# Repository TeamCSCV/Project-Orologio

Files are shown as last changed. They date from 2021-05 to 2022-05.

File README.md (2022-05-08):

# Digital Alarm Clock

Lab project for the second semester at ENTC-UoM

The purpose of this project is to present the design and construction of a digital clock fitted with an alarm circuit that operates at a frequency of 16MHz. This digital alarm clock is designed such that it uses a keypad for giving inputs, buttons to control the menu, an LCD display to visualize current time and date, and a buzzer to ring the alarm tones. Menu options range from core clock functionalities like setting the current date and time to setting the alarm time and the alarm tones.

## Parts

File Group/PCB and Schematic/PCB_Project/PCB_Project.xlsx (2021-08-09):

Comment | Description | Designator | Footprint | LibRef | Quantity
330nF | Aluminum Electrolytic Capacitor, 100 uF, +/- 20%, 50 V, -40 to 85 degC, 2-Pin THD, RoHS, Bulk | C1 | CAPPR65-350-1150X800X1250 | CMP-1665-00042-2 | 1
100nF | Aluminum Electrolytic Capacitor, 100 uF, +/- 20%, 50 V, -40 to 85 degC, 2-Pin THD, RoHS, Bulk | C2, C5, C6 | CAPPR65-350-1150X800X1250 | CMP-1665-00042-2 | 3
22pF | Cap Ceramic 22pF 50V C0G ±5% Radial 5mm +125°C Automotive Bulk | C3, C4 | FP-RCE0K1-MFG | CMP-06035-004895-1 | 2
1N4001 | Standard Recovery Rectifier, 2-Pin Axial_Lead, Pb-Free, Bulk Bag | D1 | ONSC-AXIAL_LEAD-2-59-10_P | CMP-0902-00117-1 | 1
Power | CONN HEADER VERT 2POS 2MM | JST1 | FP-440054-2-MFG | CMP-03369-000005-1 | 1
Buzzer | CONN HEADER VERT 2POS 2MM | JST2 | FP-440054-2-MFG | CMP-03369-000005-1 | 1
Potentiometer | Male Header, Pitch 2 mm, 1 x 3 Position, Height 6 mm, Tail Length 3.4 mm, -25 to 85 degC, RoHS, Bulk | JST3 | JST-B3B-PH-K-S-3_V | CMP-2000-05164-1 | 1
UP_BTN | SWITCH TACTILE SPST-NO 0.05A 24V | KEY1 | FP-1825910-2-0 | CMP-03407-000004-1 | 1
DOWN_BTN | SWITCH TACTILE SPST-NO 0.05A 24V | KEY2 | FP-1825910-2-0 | CMP-03407-000004-1 | 1
SELECT_BTN | SWITCH TACTILE SPST-NO 0.05A 24V | KEY3 | FP-1825910-2-0 | CMP-03407-000004-1 | 1
BACK_BTN | SWITCH TACTILE SPST-NO 0.05A 24V | KEY4 | FP-1825910-2-0 | CMP-03407-000004-1 | 1
RST_BTN | SWITCH TACTILE SPST-NO 0.05A 24V | KEY5 | FP-1825910-2-0 | CMP-03407-000004-1 | 1
LCD Connector | THT Vertical Pin Header WR-PHD, Pitch 2.54 mm, Single Row, 12 pins | P1 | 61301211121 | CMP-1502-01086-1 | 1
Keypad | THT Vertical Pin Header WR-PHD, Pitch 2.54 mm, Single Row, 7 pins | P2 | 61300711121 | CMP-1502-01074-1 | 1
RTC Module | THT Vertical Pin Header WR-PHD, Pitch 2.54 mm, Single Row, 4 pins | P3 | 61300411121 | CMP-1502-01064-1 | 1
BC547B | NPN Bipolar Transistor | Q1 | ONSC-TO-92-3-29-11 | NPN | 1
1K | Resistor | R1, R2, R3, R4, R5, R6, R7, R8 | AXIAL-0.3 | Res1 | 8
470R | Resistor | R9, R10, R11 | AXIAL-0.3 | Res1 | 3
220R | Resistor | R12, R13 | AXIAL-0.3 | Res1 | 2
10K | Resistor | R14 | AXIAL-0.3 | Res1 | 1
ATmega328P-PU | 8-bit AVR Microcontroller, 32KB Flash, 1KB EEPROM, 2KB SRAM, 28-pin PDIP, Industrial Grade (-40°C to 85°C) | U1 | 28P3 | CMP-0095-00013-2 | 1
L7805ACV | Positive Voltage Regulator, 5V, 3-Pin TO-220 | U2 | TO220 | CMP-0244-00484-1 | 1
16MHz | Resistance Weld Thru-Hole Crystal, 16 MHz, -20 to 70 degC, 2-Pin THD, RoHS, Bulk | XTAL1 | FOX-FOXSLF160-20 | CMP-1749-00003-1 | 1

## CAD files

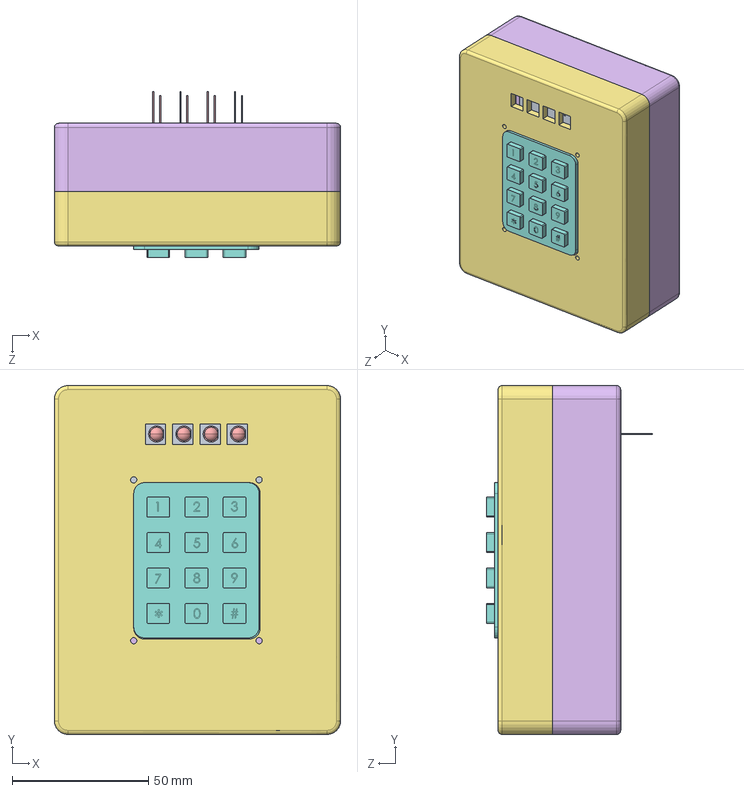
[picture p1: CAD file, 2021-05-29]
Individual/Key Input (Senuri)/Solidworks/keyInput_.SLDASM
105.0 x 128.0 x 61.0 mm
Extruded.step
Extruded-0.step x 2
Extruded-1.step x 2
Extruded-2.step x 4
Extruded-3.step x 2
Extruded-4.step x 2
Extruded-5.step x 2
Extruded-6.step x 2
Extruded-7.step x 4
Extruded-8.step x 2
Extruded-9.step x 2
Extruded-10.step x 4
Extruded-11.step x 2
Extruded-12.step x 2
Extruded-13.step
Extruded-14.step
Extruded-15.step x 3
Extruded-16.step x 3
Extruded-17.step
WP7113.step x 4
test_bottom
test_top
Keypad 3x4.step
9V Battery Holder

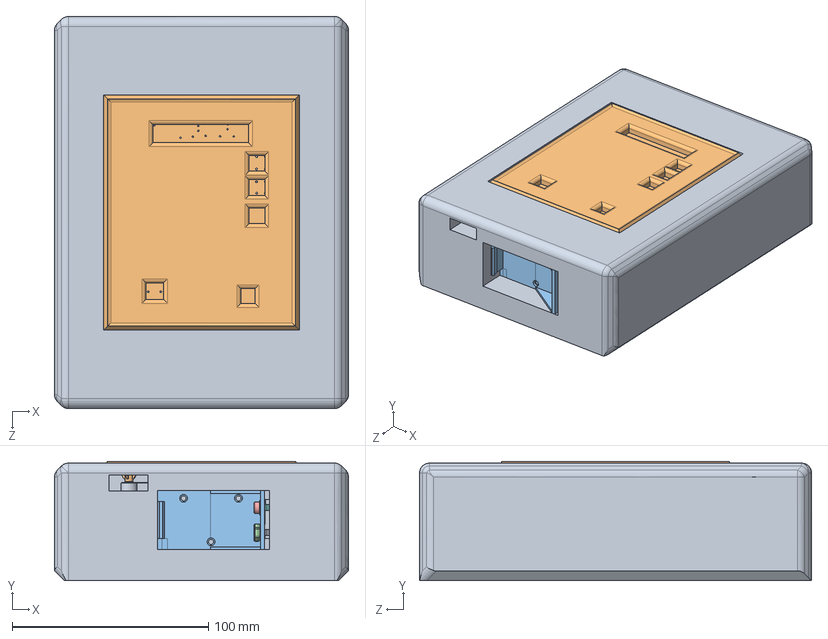
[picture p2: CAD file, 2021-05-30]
Individual/Alarm Timing (Vinuja)/Solidworks enclosure/ProjectAssembly.SLDASM
150.0 x 60.9 x 200.0 mm
labProject_micro_bottom
Body_Housing.step
Body_Anode.step
Body_Cathode.step
Eyelet_bended_Cathode.step
Eyelet_bended_Anode.step
labProject_micro_top

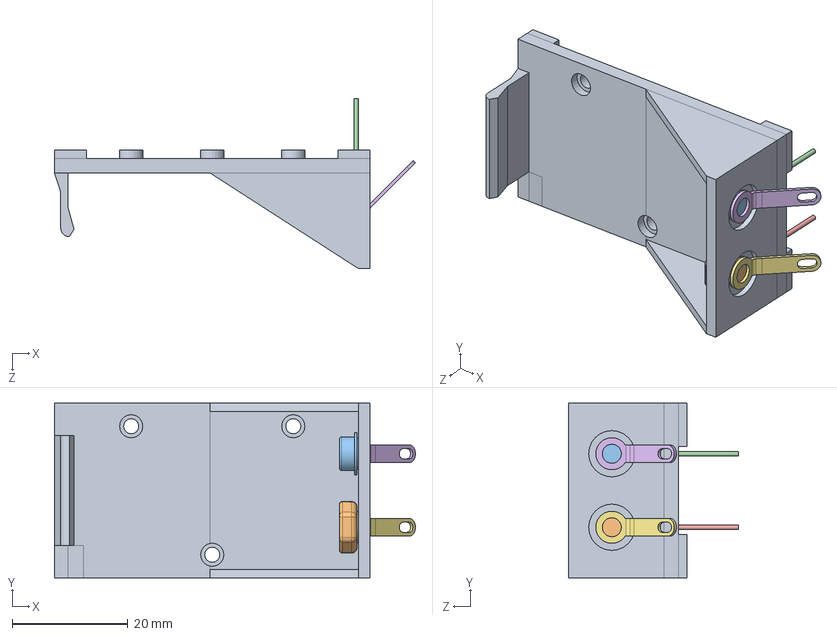
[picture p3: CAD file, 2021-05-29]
Individual/Alarm Timing (Vinuja)/Solidworks enclosure/BatteryHolder_9V_Eyelet_or_Pins.SLDASM
62.4 x 30.2 x 29.4 mm
Body_Housing.step
Body_Anode.step
Body_Cathode.step
Eyelet_bended_Cathode.step
Eyelet_bended_Anode.step

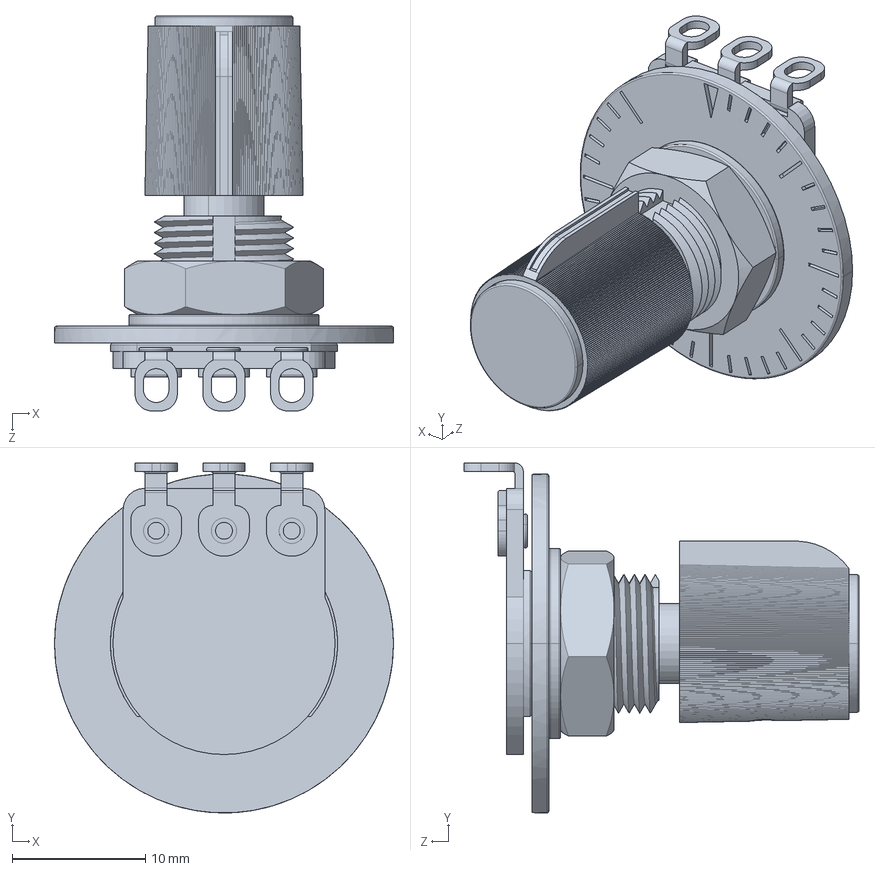
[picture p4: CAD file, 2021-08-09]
Group/Enclosure/100 ohm Sigle Potentiometer Assembly.SLDPRT
25.4 x 26.2 x 29.6 mm

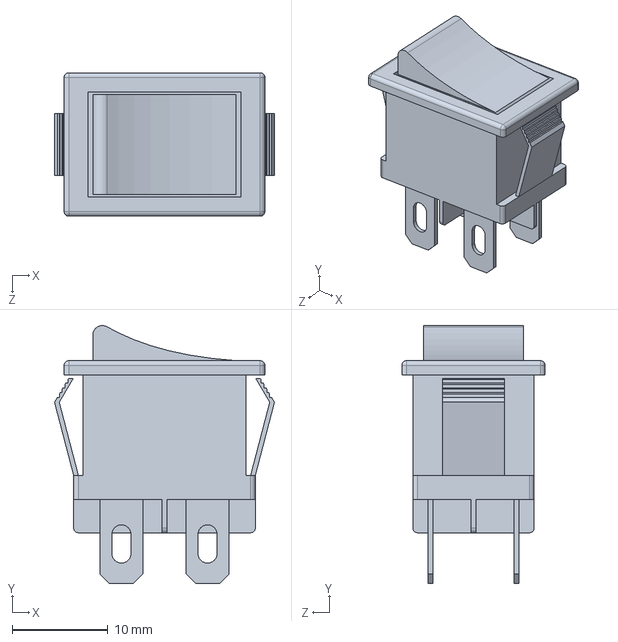
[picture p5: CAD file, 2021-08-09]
Group/Enclosure/64_Switch.step.SLDPRT
23.0 x 27.0 x 15.0 mm

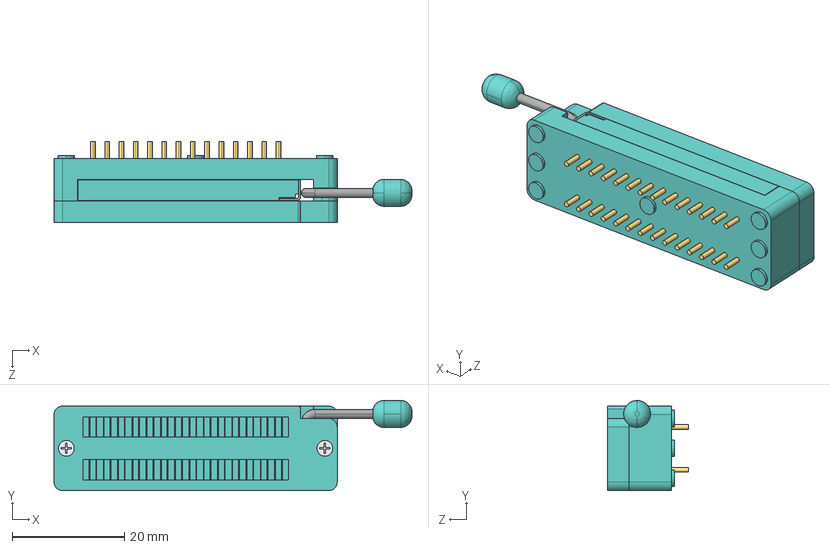
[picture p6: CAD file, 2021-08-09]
Group/PCB and Schematic/PCB_Project/Models/User Library-ZIF-Socket-28-pin.STEP
63.7 x 16.0 x 14.4 mm
Contacts
Pins001
Screw002
Bottom-Shape
Lever-Tip
Top-Shape
Push-Bar
Lever-Bar
Screw001

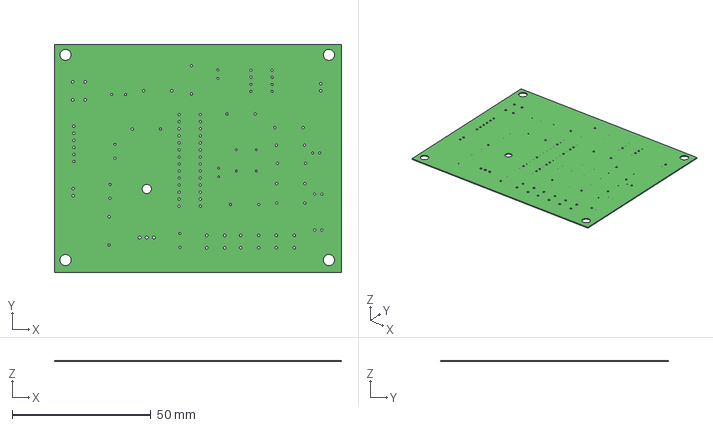
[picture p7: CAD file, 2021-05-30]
Individual/Alarm Timing (Vinuja)/Solidworks enclosure/AlarmTiming.step
103.5 x 82.2 x 0.411 mm

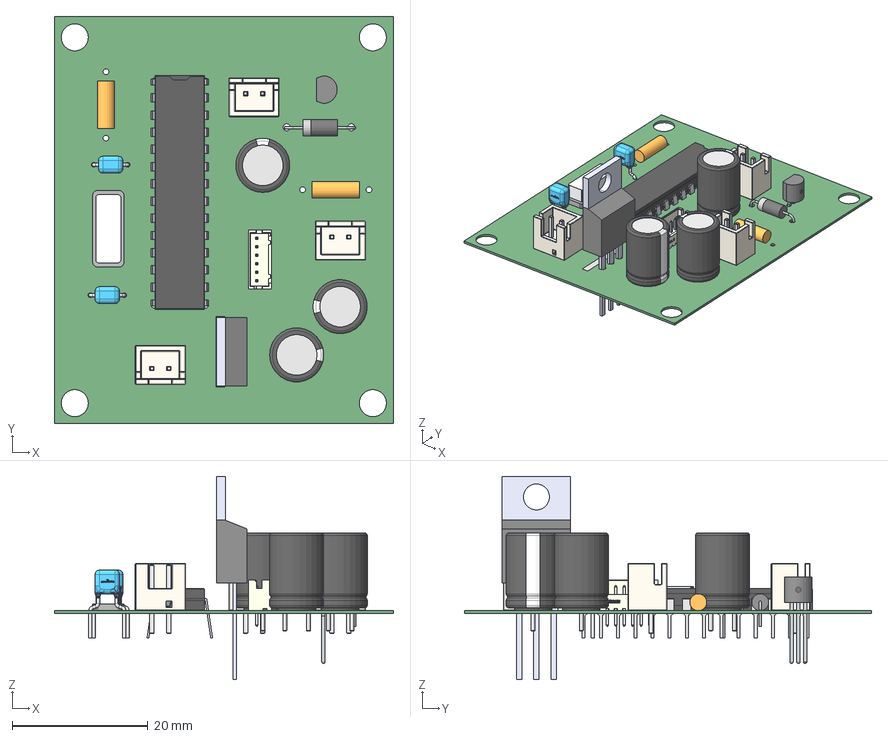
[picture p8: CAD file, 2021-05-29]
Individual/Audio Output (Chathushka)/2nd Stage/Solid Works/PCB1.step
50.0 x 60.1 x 30.0 mm
B2B-XH-A x 3
JST_Logo_adjustable x 3
L7805ACV
Extruded x 3
atmega328p-pu
BC547-B
M30-610XXXX_MOULDING
M30-610XXXX_PIN x 6
Harwin
Aluminum_electrolytic_capacitor_radial_D8_H11.5_PinD0.6_Pitch3.5_ nominal_black x 15
leads x 2
logo x 2
Diode_1N4001

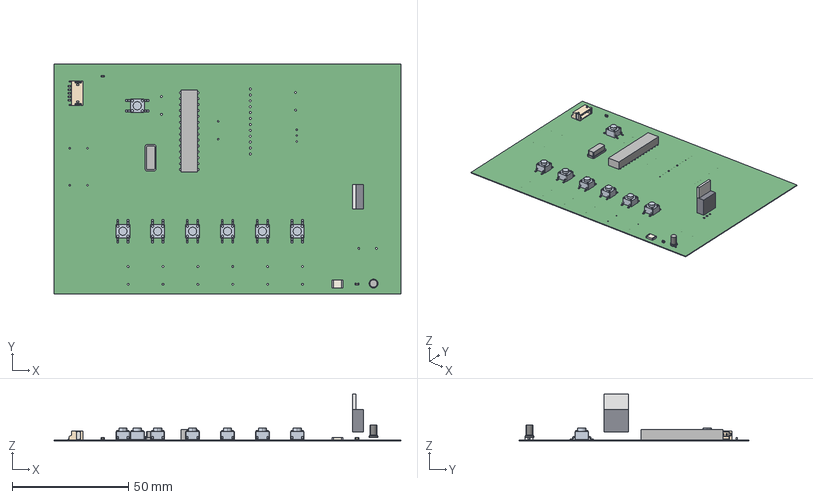
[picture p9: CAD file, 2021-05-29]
Individual/Display (Chamith)/PCB_Project/PCB1.step
149.2 x 99.1 x 20.1 mm
6481xx131822_PIN x 5
6481xx131822_PATTE x 2
TDK_Logo x 2
Extruded x 11
c-4-1437565-2-s-3d x 7

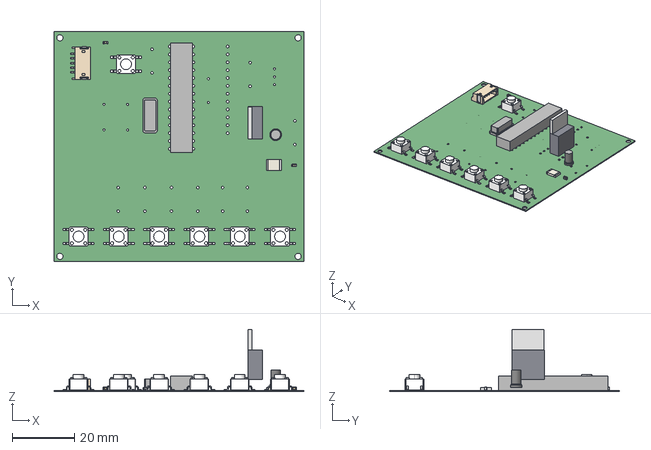
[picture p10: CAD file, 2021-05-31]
Individual/Display (Chamith)/Solidworks file/PCB2.step
80.6 x 74.2 x 20.1 mm

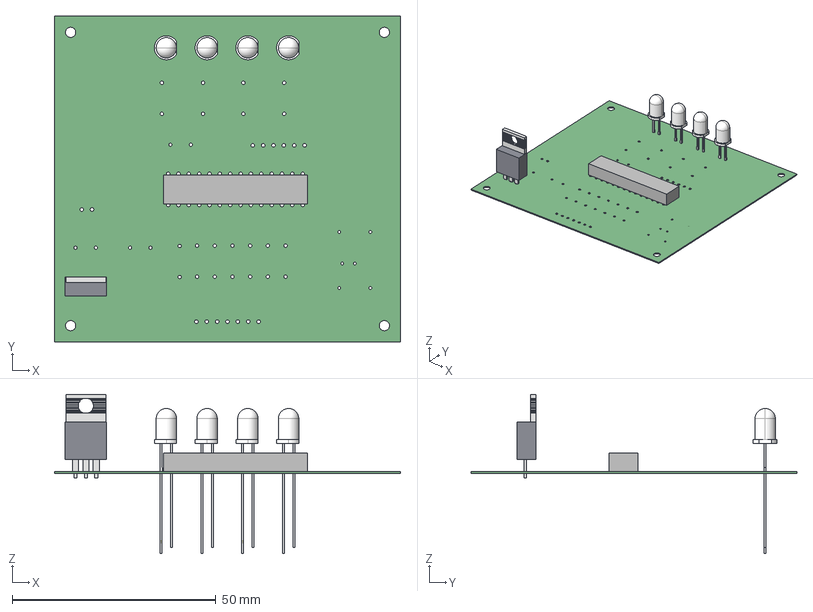
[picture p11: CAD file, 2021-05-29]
Individual/Key Input (Senuri)/PCB-KeyInput/keyInput1.step
85.0 x 80.0 x 39.1 mm
Extruded x 42
WP7113 x 4

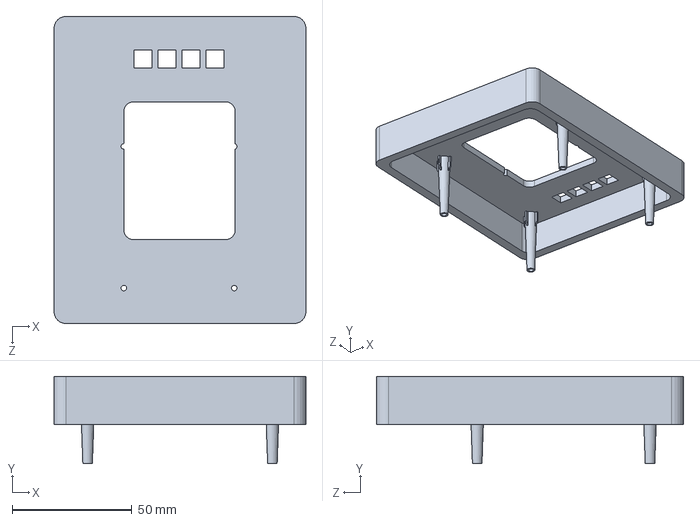
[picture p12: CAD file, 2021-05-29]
Individual/Key Input (Senuri)/Solidworks/test_top.SLDPRT
105.0 x 36.3 x 128.0 mm

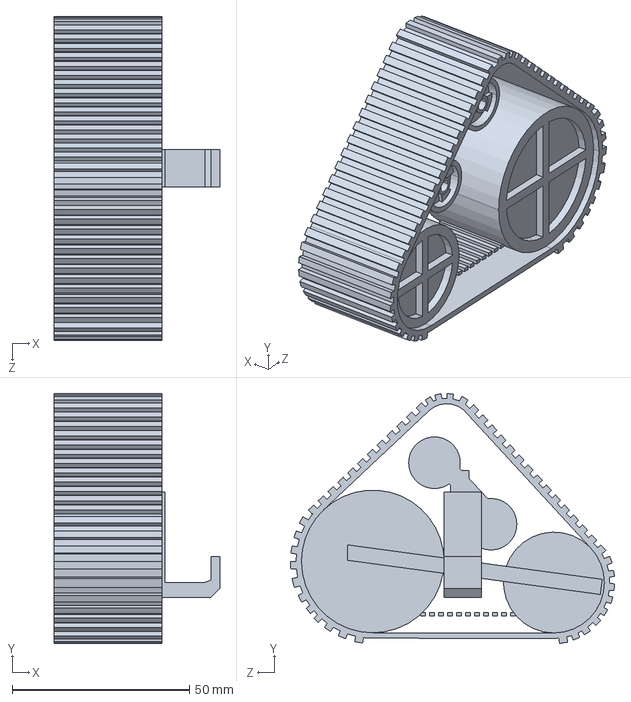
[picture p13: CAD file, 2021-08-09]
Group/Enclosure/wheel 2.SLDPRT
46.7 x 70.5 x 91.4 mm

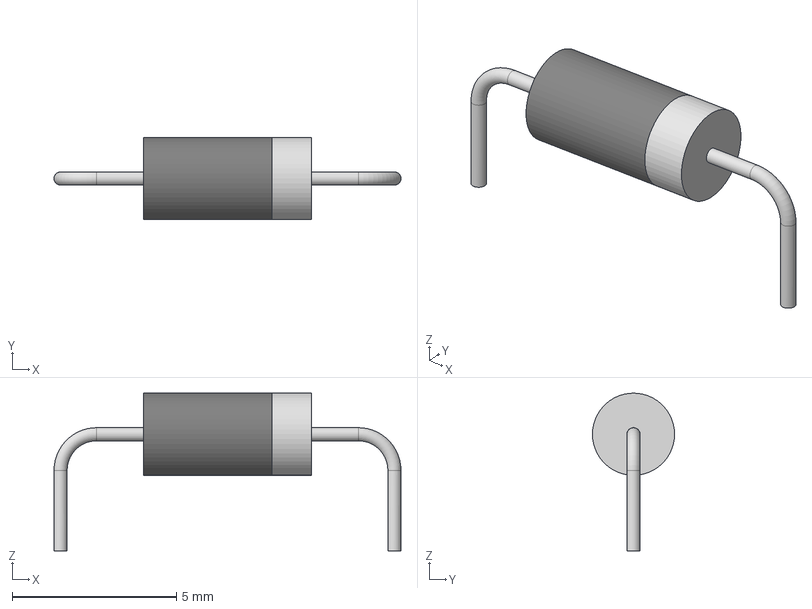
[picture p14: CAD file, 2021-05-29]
Group/PCB and Schematic/PCB_Project/Models/Diode 1N4001.stp
10.6 x 2.50 x 4.80 mm

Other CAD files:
Individual/Alarm Timing (Vinuja)/Solidworks enclosure/Open CASCADE STEP translator 6.8 6.1.1.step.SLDPRT
Individual/Audio Output (Chathushka)/2nd Stage/Solid Works/Bouton poussoir.SLDPRT
Individual/Display (Chamith)/PCB_Project/PCB2.step
Individual/Display (Chamith)/Solidworks file/smt_resistor222.STEP.SLDPRT
Group/Enclosure/64_Switch.STEP
Group/Enclosure/BATTARY HOLDER.SLDPRT
Group/Enclosure/Matrix Keypad 12 Key (4X3).SLDPRT
Group/Enclosure/MirrorRight Side Arm.SLDPRT
Group/Enclosure/Mirrorwheel 2.SLDPRT
Group/Enclosure/Part46.SLDPRT
Group/Enclosure/Part5.SLDPRT
Group/Enclosure/Right Side Arm.SLDPRT
Group/Enclosure/Right Side Arm.STEP
Group/Enclosure/TMB12A05.step
Group/Enclosure/TMB12A05.step.SLDPRT
Group/Enclosure/upper part.SLDPRT
Group/Enclosure/wheel.STEP
Group/PCB and Schematic/PCB_Project/Models/1N4001--3DModel-STEP-56544.STEP
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

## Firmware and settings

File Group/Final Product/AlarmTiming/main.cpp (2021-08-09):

#define __DELAY_BACKWARD_COMPATIBLE__
#define F_CPU 1000000UL

#include <avr/io.h>
#include <stdlib.h>
#include <stdio.h>
#include "ds1307.h"
#include "Settings.h"
#include "util/delay.h"
#include "Screen.h"
#include "Key_Pad.h"
#include "Tone.h"


Screen scrn;
Key_Pad key;
Tone t(3);


int main(void)
{
	ds1307_init();
	scrn.LCD_Init();
	while (1)
	{
		

		mainLoop();
			
	
	}
		
	
}

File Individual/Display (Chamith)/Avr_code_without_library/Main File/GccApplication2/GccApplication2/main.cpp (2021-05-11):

/*
 * display.cpp
 * Created by Ranathunga R.A.C.D 190501V
 */ 

#include <avr/io.h>
#define F_CPU 1000000UL			
#include <avr/io.h>			
#include <util/delay.h>			

#define LCD_Dir  DDRB			//LCD data port direction
#define LCD_Port PORTB			//LCD data port
#define RS PB0				   //register select pin
#define EN PB1 				  // Enable pin


void LCD_Command( unsigned char cmnd )     //function to initialize a command given as a hexadecimal number
{
	LCD_Port = (LCD_Port & 0x0F) | (cmnd & 0xF0); 
	LCD_Port &= ~ (1<<RS);		
	LCD_Port |= (1<<EN);		
	_delay_us(1);
	LCD_Port &= ~ (1<<EN);

	_delay_us(200);

	LCD_Port = (LCD_Port & 0x0F) | (cmnd << 4); 
	LCD_Port |= (1<<EN);
	_delay_us(1);
	LCD_Port &= ~ (1<<EN);
	_delay_ms(2);
}



void LCD_Char( unsigned char data )
{
	LCD_Port = (LCD_Port & 0x0F) | (data & 0xF0); 
	LCD_Port |= (1<<RS);		//RS = 1
	LCD_Port|= (1<<EN);
	_delay_us(1);
	LCD_Port &= ~ (1<<EN);

	_delay_us(200);

	LCD_Port = (LCD_Port & 0x0F) | (data << 4); 
	LCD_Port |= (1<<EN);
	_delay_us(1);
	LCD_Port &= ~ (1<<EN);
	_delay_ms(2);
}



void LCD_Init (void)			//Initialize the display
{
	LCD_Dir = 0xFF;			//LCD data direction is output
	_delay_ms(20);			
	
	LCD_Command(0x02);		
	LCD_Command(0x28);              
	LCD_Command(0x0c);              //Command - Display on Cursor off
	LCD_Command(0x06);              //Command - shift cursor to right
	LCD_Command(0x01);              //Command - Clear display
	_delay_ms(2);
}




void LCD_String (char *str)		//Writing a string on LCd display
{
	int i;
	for(i=0;str[i]!=0;i++)		
	{
		LCD_Char (str[i]);
	}
}



void LCD_Clear()             //Function to clear display and come back to home position
{
	LCD_Command (0x01);		
	_delay_ms(2);
	LCD_Command (0x80);		
}


void Time()             //Function to write time to display(Here I have used the test "Time". (I have to link RTC code here)
{
	LCD_Clear();
	LCD_String("Time...");
	_delay_ms(500);
}


void Select()            //What to do when the user press the select button
{
	LCD_Clear();
	LCD_String("Pressed Select");
	_delay_ms(500);
}

void Left()              //What to do when the user press the left arrow
{
	LCD_Clear();
	LCD_String("Pressed Left");
	_delay_ms(500);
}

void Right()              //What to do when the user press the right arrow
{
	
	LCD_Clear();
	LCD_String("Pressed Right");
	_delay_ms(500);
}

void Up()                  //What to do when the user press the up arrow
{
	LCD_Clear();
	LCD_String("Pressed Up");
	_delay_ms(500);
}

void Down()              //What to do when the user press the down arrow
{
	LCD_Clear();
	LCD_String("Pressed Down");
	_delay_ms(500);
}

void Back()             //What to do when the user press the back button
{
	LCD_Clear();
	LCD_String("Pressed Back");
	_delay_ms(500);
}

int main(void)           //main function continuously looks for a signal from the user
{
    DDRD = 0x00;
	LCD_Init();
	Time();
    while (1) 
    {
		if (PIND == 0x01){
			Select();
		}
		else if (PIND == 0x02){
			Left();
		}
		else if (PIND == 0x04){
			Down();
		}
		else if (PIND == 0x08){
			Up();
		}
		else if (PIND == 0x10){
			Right();
		}
		else if(PIND == 0x20){
			Back();
		}
	}
}

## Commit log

2021-03-30 Updated two more alarm tones to the library & Added a simple basic schematic(Buzzer,Arduino board)
    [Tone.cpp, src.ino]
2021-03-31 Updated 1 alarm tone(4+1) and rearranged the schematic by adding a button to press
2021-04-01 Added four buttons to the micro product and assigned them commands to go thorough the Menu. Also added the schematic layout proteus file.
2021-04-01 Updated the src file and library files such that alarm tone can be changed using the button, Replaced uno board due to insufficient storage
    [Tone.cpp, src.ino]
2021-04-02 Added the schematic layout proteus file of key input and added new changes to the code
2021-04-03 Added the code for arduino library of key input
2021-04-06 Reduced the length of the alarm tones to fix error due to insufficient memory , Used arduino uno again
    [Tone.cpp, src.ino]
2021-04-06 Created my own library named Display and changed the arduino code using my new library. Added a word file containing the messages to be displayed at the different stages of clock
2021-04-07 Wrote a short description about the library
    [Tone.cpp, src.ino]
2021-04-19 I found that there was an error in my logic. I hadn't clearly explained how to select a particular option from my menu. Therefore I changed the layout of the menu. And then started the alarm changing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
    [Display.cpp, display_chamith.ino]
2021-04-24 Initial AVR C++ code with errors
    [Tone.cpp, main.cpp]
2021-05-11 Added some changes to the keyinput library code and added the schematic file
2021-05-11 Added PCB Schematic and Layout (Altium)
    [Audio_Output.PrjPcb, PCB1.PcbDoc, Sheet1.SchDoc]
2021-05-14 avr codes,proteus simulation schematics and solidworks
    [labProject_micro.STEP]
2021-05-15 Added PCB schematic and PCB layout
2021-05-16 Added PCB schematic and PCB layout files
    [PCB-KeyInput.PrjPcb, keyInput.PcbDoc, keyInput.SchDoc]
2021-05-17 sorted avr code with new class and sorted the proteus schematic
2021-05-19 added pcb schematic and layout
    [AlarmTiming.PcbDoc, AlarmTiming.PrjPcb, AlarmTiming.SchDoc]
2021-05-21 Added the pcb project file
    [PCB_Project.PrjPcb, Sheet1.SchDoc]
2021-05-21 Updated some circuit components
    [1N4001--3DModel-STEP-56544.STEP, Aluminum_electrolytic_capacitor_radial_D8_H11.5_PinD0.6_Pitch3.5_nominal_black.step, Audio_Output.PrjPcb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]
2021-05-21 Added my solidwork sketches(can be edited)
    [labProject_micro.STEP, labProject_micro_bottom.SLDPRT, labProject_micro_bottom.STEP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]
2021-05-22 Updated PCB and added Solid works design(incomplete)
    [4 BATTERY PACK.SLDPRT, 64_Switch.STEP, Bouton poussoir.SLDPRT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]
2021-05-22 Modified the pcb schematic and layout of keyinput
    [PCB-KeyInput.PrjPcb, keyInput.PcbDoc, keyInput.SchDoc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]
2021-05-22 Added solidworks files for keyinput enclosure
    [9V Battery Holder.SLDPRT, Keypad 3x4.STEP, keyInput_.SLDASM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]
2021-05-22 Updated the PCB file
    [PCB1.PcbDoc, PCB_Project.PrjPcb, Sheet1.SchDoc]
2021-05-22 Updated the Solid Works Design
    [BATTARY HOLDER.SLDPRT]
2021-05-23 Modified the enclosure for keyinput
    [9V Battery Holder.SLDPRT, Keypad 3x4.STEP, keyInput_.SLDASM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]
2021-05-27 Created a second PCB board with less width and height
    [PCB1.PcbDoc, PCB1.step, PCB2.PcbDoc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]
2021-05-29 Added the solidworks file
    [BatteryHolder_9V_Eyelet_or_Pins.SLDASM, PCB2.step, base1.SLDPRT]
2021-05-29 Modified some files in the keyinput folder
    [keyInput.PcbDoc, keyInput.SchDoc, keyInput_.SLDASM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]
2021-05-29 Modified the enclosure and updated the schematic
    [4 BATTERY PACK.SLDPRT, PCB1.PcbDoc, Sheet1.SchDoc]
2021-05-30 2nd evaluation final submission
    [AlarmTiming.PcbDoc, AlarmTiming.PrjPcb, AlarmTiming.SchDoc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]
2021-05-30 Rearranged the directories and finalized
    [1N4001--3DModel-STEP-56544.STEP, 64_Switch.STEP, Aluminum_electrolytic_capacitor_radial_D8_H11.5_PinD0.6_Pitch3.5_nominal_black.step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]
2021-05-30 Modified the solidworks file and make some changes in the pcb
    [16pin_header__.STEP.SLDPRT, PCB2.PcbDoc, PCB2.step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]
2021-06-06 Added incompleted Schematic
    [PCB1.PcbDoc, PCB_Project.PrjPcb, Sheet1.SchDoc]
2021-06-07 Updated schematic
    [PCB1.PcbDoc, PCB_Project.PrjPcb, Sheet1.SchDoc]
2021-06-07 Designed the PCB layout(incomplete)
    [PCB1.PcbDoc, PCB_Project.PrjPcb, Sheet1.SchDoc]
2021-06-09 Optimized the code for the final product
    [PCB2.PcbDoc]
2021-06-09 Modified the PCB layout
    [PCB1.PcbDoc, PCB_Project.PrjPcb]
2021-06-21 Updated the code (ringing,about,idle mode) and started to design the enclosure
2021-08-03 Modified Enclosure(Added Wheels,tray and a button
    [Matrix Keypad 12 Key (4X3).SLDPRT, Part46.SLDPRT, wheel 2.SLDPRT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]
2021-08-04 Updated the Lower Part
    [wheel 2.SLDPRT]
2021-08-07 Fixed the about us content
    [main.cpp]
2021-08-08 Added the finalized PCB
    [1N4001--3DModel-STEP-56544.STEP, Aluminum_electrolytic_capacitor_radial_D8_H11.5_PinD0.6_Pitch3.5_nominal_black.step, BC547-B.step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]
2021-08-09 Finalized the enclosure
    [100 ohm Sigle Potentiometer Assembly.SLDPRT, 64_Switch.STEP, 64_Switch.step.SLDPRT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]
